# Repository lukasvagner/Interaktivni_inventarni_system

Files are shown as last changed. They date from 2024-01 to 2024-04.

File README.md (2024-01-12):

# Interaktivní inventární systém
## Anotace:
Bylo by to sledování krabiček. Systém by měl využívat vývojovou desku Raspberry Pi Zero, na které běží webserver. Tento webserver umožní vidět, které položky chybí a kdo si je vypůjčil. 
Každá krabička by měla své místo ve skříni a bude fungovat jako šuplík. U každého šuplíku by byl umístěn senzor, pravděpodobně infračervený (IR), který by sledoval, zda je krabička na svém místě. Dále by byla RGB LED pro zobrazování stavu a navigaci, kde danou položku vrátit.
Když uživatel vyjme krabičku, bude potřebovat se přihlásit tím, že přiloží svou identifikační kartu (RFID) k čtečce, kterou běžně používá ve škole. Tato informace spolu s číslem nebo názvem krabičky bude uložena do databáze spolu s datem a časem výpůjčky.

## Hardware
Budeme používat několik komponentů:
<ol>
  <li>Mozek všeho raspberry pi zeroWH - <a href="https://rpishop.cz/raspberry-pi-zero/685-raspberry-pi-zero-wh-4250236816296.html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">RPIShop</a><ul>
  <li>W značí že obsahuje čip na bezdrátové rozhraní</li>
  <li>H značí předem instalovaný header</li>
  
  </ul></li>
  <li>Nfc/Rfid čtečka na karty</li>
  <li>Senzor světla <ul>
    <li>Budeme nejspíš používat TCRT5000 - <a href="https://pdf1.alldatasheet.com/datasheet-pdf/download/26406/VISHAY/TCRT5000.html">DATASHEET</a></li>
    <li>používá se jako senzor ke kontrole zda jsou krabičky uloženy či nikoliv</li>
  </ul>
  </li>
  <li>Individuálně adresovatelné diody WS2812B k navigaci kam vracet krabičky<a href="https://pdf1.alldatasheet.com/datasheet-pdf/download/1179113/WORLDSEMI/WS2812B.html">DATASHEET</a> </li>
</ol>
 
## Funkčnost
Po přiložení karty načtená karta na 5s v této době si můžete vzít co chcete a bude ulozeno id karty pro případné problémy.
Při vracení karta neni potřeba jen načtete rfid chip na boxu a vložíte box na místo kde bliká led.
### Stavy
<ul>
<li>zelená: Box na svém místě</li>
<li>červená: Box ukraden nebo vložen na špatné místo</li>
<li>modrá: Box vypůjčen správně</li>
<li>oranžová: Box vypůjčen zatím není nahrána karta je tam čas 10sna to ji nahrát</li>
<li>blikající oranžová: Značí na jaké místo box vrátit</li> 
</ul>

## Progress update:
<ul>
  <li>30.11.23- Objednáno RaspberryPi Zero W</li>
  <li>15.12.23- Objední zbytku</li>
  <li>26.12.23- Funkční systém se čtečkou nfc a jedním senzorem</li>
  <li>02.01.24- Funkční systém se základním výpisem na server a psaní data logu do .txt</li>
  <li>04.01.24- Všechno přišlo</li>
  
</ul>

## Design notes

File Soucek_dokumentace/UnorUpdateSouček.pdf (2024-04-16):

## Vyšší odborná škola

a Střední průmyslová škola elektrotechnická,

## Plzeň, Koterovská 85

## Ročníková práce s obhajobou

Téma: | Inteligentní Inventární systém
Autor práce: | Jakub Souček
Třída: | 3.M
Vedoucí práce: | Prof. Ing. Pavel Jedlička
Dne: | 31.1.2024

## Hodnocení:

## Z A D Á N Í R O Č N Í K O V É P R Á C E

Školní rok | 2023/ 2024
Studijní obor | 78-42-M/01 Technické lyceum
Jméno a příjmení | Jakub Souček
Třída | 3.M
Předmět | Kybernetika
Hodnoceno v předmětu | Kybernetika
Téma | Inventární systémy
Obsah práce | • Návrh velikosti a tvaru krabiček o • Hardwarová část • nakoupení potřebných součástek, propojení senzorů a ledek s mikropočítačem. • Uživatelské rozhraní • zavedení přihlašovacího systému s kartami/čipy • Vytvoření webového rozhraní pro sledování stavu krabiček • zjišťování chybějících položek a ovládání funkcí
Zadávající učitel Příjmení, jméno | Jedlička Pavel

## Podpis zadávajícího učitele

Termín odevzdání | 30. dubna 2024

## Vyšší odborná škola a

Střední průmyslová škola elektrotechnická Plzeň,

## Koterovská 85

V Plzni dne: 30. 11. 2023 | Mgr. Vlas]mil Volák ředitel školy

## Anotace

Cílem této rovníkové práce by bylo vyrobit systém, který by kontroloval, kdo a kdy si vypůjčil nějakou položku ze skříně. Jednotliví lidé by se ověřovali stejnou identifikační kartou jako používají ve školním systému doposud. Dále by byla možnost podívat se na obsah skříně online na webserveru, ve kterém by byla vidět všechna data o různých Výpůjčkách jako je: čas a UID karty uživatele.

„Prohlašuji, že jsem tuto práci vypracoval samostatně a použil(a) literárních pramenů a informací, které cituji a uvádím v seznamu použité literatury a zdrojů informací.“

V Plzni dne: | Podpis:

## Obsah

1 Úvod | 5
2 Návrh | 5

4

## 1 Úvod

Jako žák prestižní střední školy SPŠE vnímám jako závažný problém, kterým je „bordel“ v úložném

prostoru v učebnách dílen. Jeden z hlavních problému jsou neustálé ztráty součástek a časté krádeže výukového materiálu. Proto jsem se já a můj kamarád Lukáš Vágner s tímto problémem něco udělat. Tento systém umožňuje sledování obsahu inventáře prostřednictvím Optických senzorů, které detekují přítomnost předmětů v určité vzdálenosti. Jeho potenciál spočívá v prevenci krádeží a monitorování obsahu skříně. Cílem této ročníkové práce je navrhnout a implementovat inteligentní inventární systém, schopný detekovat předměty v blízkosti senzorů TCRT-5000. Účelem

je vytvořit funkční prototyp, který monitoruje obsah skříně a poskytuje informace o přítomnosti a množství jednotlivých předmětů. Tento systém může najít uplatnění v různých oblastech, včetně skladů, kanceláří a domácností. Pokud máte další otázky, neváhejte se zeptat. Děkuji za upřesnění ohledně použití NFC čipů a přístupových karet. Tyto technologie využívají bezkontaktní přenos dat prostřednictvím rádiových vln¹²³. Jsou běžně využívány v přístupových a docházkových sys-

témech a mohou být aplikovány i ve Vašem projektu pro označení vypůjčených předmětů. bla bla bla dále to domyslím/přepíšu

2 | Návrh
2.1 | Hardware

5

2.1.1 Výběr komponentů

- Raspberry Pi Zero WH
- Miniaturní velikost: Raspberry Pi Zero WH je extrémně kompaktní počítač, který se
| vejde do rozměrů pouhých (66,0 mm x 30,5 mm x 5,0 mm). Tato malá velikost je ideální
| přesně pro níš projekt.
- Bezdrátová konektivita: Raspberry Pi Zero WH je vybaven Wi-Fi 802.11n a Bluetooth
| 4.1, což umožňuje snadnou komunikaci s jinými zařízeními.
- GPIO piny: Na desce je 40 GPIO pinů, které umožňují připojení dalších periferií a
| rozšíření.

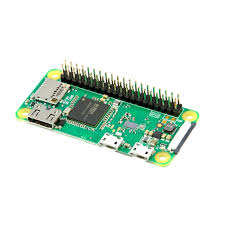
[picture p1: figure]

Obrázek 1: : Raspberry Pi Zero WH

6

- Pn532 - NFC/RFID čtečka karet
- Frekvence a podpora NFC tagů: NFC čtečka tagů PN532 pracuje na frekvenci 13,56 MHz a podporuje takzvané NFC tagy. Za tagy se považují všemožné RFID karty, žetony, samolepky atd.
- Rozhraní: NFC čtečka PN532 umí komunikovat pomocí tří různých rozhraní: HSU, I2C a SPI. Můžete si vybrat to, které nejlépe vyhovuje vašemu projektu.
- Jednoduchost zapojení: Pro úspěšné propojení NFC čtečky s Raspberry stačí zapojit celkem čtyři vodiče. Propojíme GND se zemí Arduina, VCC s 3V3 Arduina, SDA s pinem A4 a SCL s pinem A5.

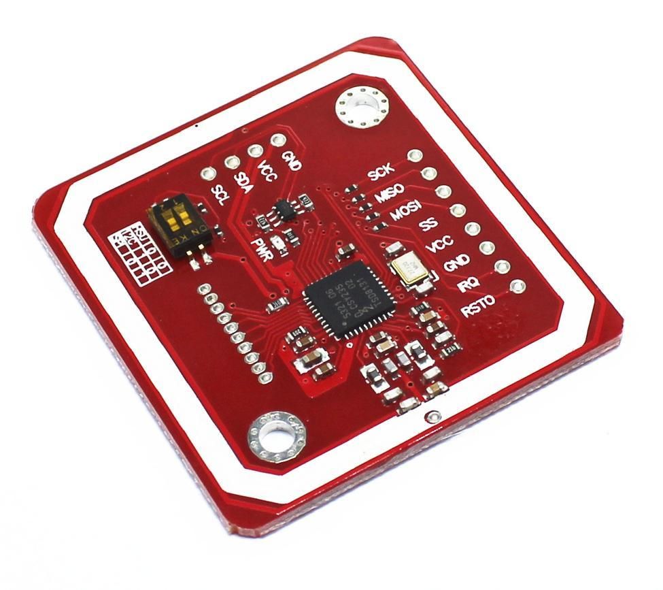
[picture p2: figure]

Obrázek 2: : Pn532 - NFC/RFID čtečka karet

7

- Pcf-8575 - 16bit I/O expander pinů připojený přes 12C
- Rozšiřuje počet I/O pinů: PCF8575 je 16bitový I/O expander, který umožňuje rozšíření počtu vstupně/výstupních pinů. Tuhle součástku jsme právě proto vybrali.
- Komunikace přes I2C: PCF8575 komunikuje pomocí sběrnice I2C (Inter-Integrated Circuit). Tato dvousměrná sběrnice umožňuje snadnou komunikaci s mikrokontroléry a dalšími zařízeními.
- Napájení: PCF8575 pracuje v rozmezí napětí od 2,5 V do 5,5 V. To znamená, že je vhodný pro různé napájecí úrovně.

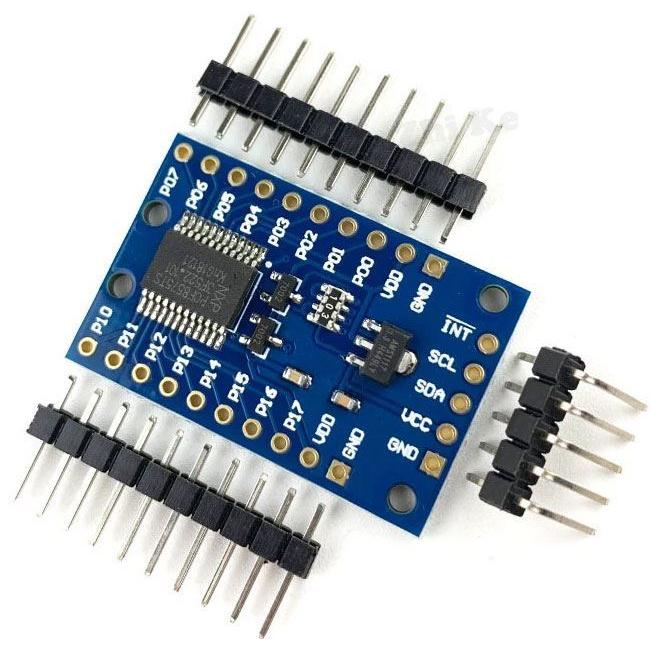
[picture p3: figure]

Obrázek 3: : 16-bit expander Pcf-8575

8

- TCRT-5000 - Infračervený optický senzor
- Reflektivní optický senzor: TCRT5000 je reflektivní senzor, což znamená, že kombinuje infračervený vysílač a fototranzistor v jednom pouzdře. Tento senzor je určen k detekci odrazů světla od povrchů.
- Pracovní vzdálenost: Má špičkovou pracovní vzdálenost 2,5 mm. To znamená, že může detekovat předměty ve vzdálenosti až 2,5 mm od senzoru.
- Filtr blokující denní světlo: TCRT5000 je vybaven filtrem, který blokuje viditelné světlo.
- Jednoduchost zapojení: Senzor se připojuje skrz desku a pracuje s napětím 5 V.

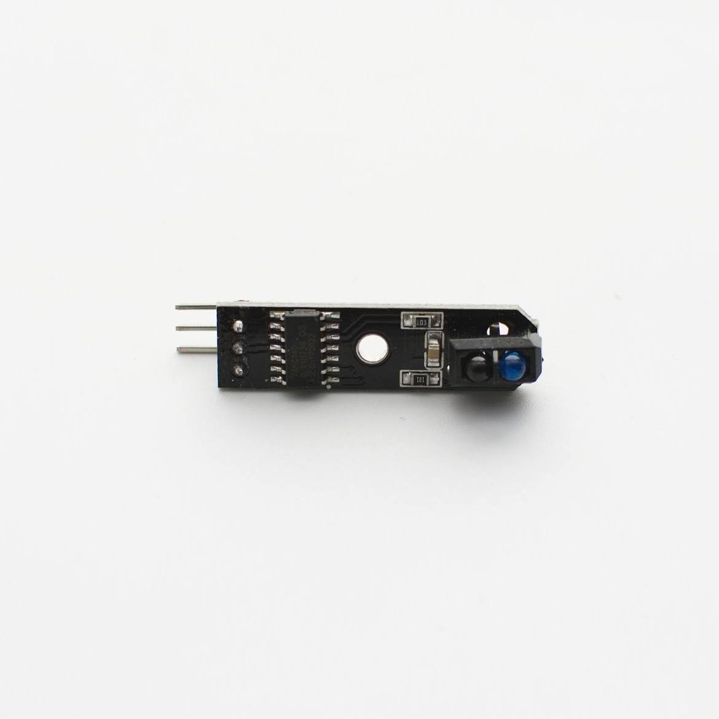
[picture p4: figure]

Obrázek 4: : Optický senzor TCRT-5000

9

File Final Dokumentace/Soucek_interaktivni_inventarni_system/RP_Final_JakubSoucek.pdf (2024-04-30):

## Vyšší odborná škola

a Střední průmyslová škola elektrotechnická,

## Plzeň, Koterovská 85

## Ročníková práce s obhajobou

Téma: | Inteligentní Inventární systém
Autor práce: | Jakub Souček
Třída: | 3.M
Vedoucí práce: | Prof. Ing. Pavel Jedlička
Dne: | 30.4.2024

## Hodnocení:

## Z A D Á N Í R O Č N Í K O V É P R Á C E

Školní rok | 2023/ 2024
Studijní obor | 78-42-M/01 Technické lyceum
Jméno a příjmení | Jakub Souček
Třída | 3.M
Předmět | Kybernetika
Hodnoceno v předmětu | Kybernetika
Téma | Inventární systémy
Obsah práce | • Návrh velikosti a tvaru krabiček o • Hardwarová část • nakoupení potřebných součástek, propojení senzorů a ledek s mikropočítačem. • Uživatelské rozhraní • zavedení přihlašovacího systému s kartami/čipy • Vytvoření webového rozhraní pro sledování stavu krabiček • zjišťování chybějících položek a ovládání funkcí
Zadávající učitel Příjmení, jméno | Jedlička Pavel

## Podpis zadávajícího učitele

Termín odevzdání | 30. dubna 2024

## Vyšší odborná škola a

Střední průmyslová škola elektrotechnická Plzeň,

## Koterovská 85

V Plzni dne: 30. 11. 2023 | Mgr. Vlas]mil Volák ředitel školy

## Anotace

Cílem této ročníkové práce je vyrobit systém, který by kontroloval, kdo a kdy si vypůjčil nějakou položku ze skříně. Jednotliví lidé by se ověřovali stejnou identifikační kartou jako se používá ve školním systému doposud. Dále by byla možnost se podívat na obsah skříně online na webserveru, ve kterém by byla vidět všechna data o různých výpůjčkách jako je: čas a UID karty uživatele.

„Prohlašuji, že jsem tuto práci vypracoval samostatně a použil literárních pramenů a informací, které cituji a uvádím v seznamu použité literatury a zdrojů informací. Souhlasím s využitím mé práce učiteli VOŠ a SPŠE Plzeň k výuce.“

V Plzni dne: | Podpis:

## Obsah

1 Úvod | 5
2 Návrh | 5
3 Hardware | 6
4 Zapojení | 9
5 3D design | 11
6 Realizace a sestavení | 13
7 Závěr | 15

4

## 1 Úvod

Naším hlavním úkolem v rámci ročníkové práce je vytvoření inteligentního inventárního systému pro školní dílny, který umožní efektivní evidenci a správu vypůjčených položek.
| Ve školních dílnách často naražíme na problémy spojené s nedbalým půjčováním nástrojů a
materiálů, což často vede k neuspořádanosti a ztrátám. Náš záměr je tuto situaci zlepšit a zajistit, aby inventář dílen byl lépe spravován a účinněji využíván.
| V rámci hardwarové části našeho projektu jsme vyvinuli a implementovali policový systém,
který systematicky uskladňuje a identifikuje položky prostřednictvím standardních krabic s čipy. Tento systém využívá kombinaci NFC/RFID čtečky pro rozpoznání čipů a identifikačních karet uživatelů. Kromě toho je vybaven senzory, které monitorují umístění krabic a inteligentními LED diodami, které signalizují stav položek.
| Na softwarové straně jsme vyvinuli uživatelsky přívětivý systém pro správu inventáře přes
webové rozhraní. Tento systém umožňuje snadné půjčování, vrácení a sledování položek. Díky němu mohou studenti a učitelé efektivně spravovat inventář a monitorovat výpůjčky i případné problémy s položkami.

## 2 Návrh

Zpočátku jsme zamýšleli o vytvoření jednoduchého systému, který by usnadnil uskladnění krabiček a sledování jejich stavu pomocí senzorů. Vytvořili jsme tak několik návrhů, jak by mohla taková krabička vypadat.
| Design poliček byl několikrát přepracován, než jsme našli ideální řešení. Nejprve jsme zamýšleli
vyrobit celý box na míru vytištěný na 3D tiskárně, ale z časových a hlavně i finančních důvodů jsme zvolili mnohem ekologičtější řešení. Zkompletovali jsme box z OSB desek, které se dají pořídit téměř v každém hobbymarketu. Jednotlivé poličky jsou přesně na míru nařezané plastové lišty a pomyslná záda našeho boxu jsou 3D vytištěné zarážky z PLA se zapuštěnými senzory a LED přesně upravené podle konkrétních požadavků.
| Elektroniku jsme také navrhovali s ohledem na snadnou výměnu, pokud by bylo potřeba s
důrazem na její cenovou dostupnost a spolehlivost. Tento proces návrhu prošel několika koly úprav, avšak nakonec jsme dosáhli řešení, které splňovalo naše požadavky a kritéria.

5

## 3 Hardware

Jelikož jsme se při výběru ideálních hardwarových součástek soustředili na co nejlehčí duplikaci celého modulu, vybírali jsme převážně hotové moduly a pasivní součástky. Komponenty, které jsme vybrali, mají schopnost pracovat s napájením buď 3.3V nebo 5V, což usnadňuje jejich začlenění do systému. Jako hlavní prostředek komunikace jsme zvolili I2C, což zajistí efektivní a spolehlivou výměnu dat mezi jednotlivými součástkami.

### 3.1 Komponenty

- Raspberry Pi Zero WH - Jedním z hlavních důvodů proč jsme vybrali právě tento
| jednočipový mikropočítač, je zakomponovaná anténa pro Bluetooth a Wifi, (W) díky které náš systém může v reálném čase sdílet informace s webem. Raspberry také podporuje programovací jazyk Python, ve kterém je náš kód. (Raspberry Pi Zero Dokumentace 2024)


Obrázek 1: Raspberry Pi Zero WH

6

- Pn532 - NFC/RFID čtečka karet - Pn532 je NFC čtečka tagů, která pracuje na frekvenci 13,56 MHz. Za tagy se považují všemožné RFID karty, žetony, samolepky atd. NFC čtečka Pn532 umí komunikovat pomocí tří různých rozhraní: HSU, I2C a SPI. Pro náš projekt jsme zvolili I2C pro její efektivní spolehlivou výměnu dat.(Pn532 návod 2024)


Obrázek 2: Pn532 - NFC/RFID čtečka karet

- Pcf-8575 - 16bit I/O expander pinů připojený přes I2C - PCF-8575 rozšiřuje rozsah vstupů a výstupů Raspberry Pi, což je praktické pro naši práci, kde je více senzorů. Využili jsme jeho podporu I2C rozhraní a možnost konfigurace různých adres, která umožňuje připojení více těchto expandérů k jedinému zařízení.(PCF-8575 Dokumentace 2024)


Obrázek 3: 16-bit expander Pcf-8575

7

- TCRT-5000 - Infračervený optický senzor - TCRT5000 je reflektivní senzor, což znamená, že kombinuje infračervený vysílač a fototranzistor v jednom pouzdře. Tento senzor je určen k detekci odrazů světla od povrchů. TCRT5000 je vybaven filtrem blokující denní světlo. Senzor je připojen skrz desku a pracuje s napětím 5 V. (TRTC-5000 dokumentace 2024)


Obrázek 4: Optický senzor TCRT-5000

8

### 3.2 Vedlejší komponenty

Kromě hotových modulů jsme začlenili do naší aplikace několik pasivních/vedlejších součástek:

- LED diody: Pro vizuální signalizaci různých stavů jsme využili 2 LED diody - červenou a zelenou.
- Buzzer: Pro zvukovou signalizaci jsme začlenili bzučák, který je schopen generovat různé zvukové signály podle aktuálního stavu systému. Buzzer přispívá k celkové interaktivitě a uživatelskému povědomí o událostech v systému.

## 4 Zapojení

Za použití programu Fritzing jsme sestavili schéma zapojení. Na obrázku 12

- Pcf-8575 - 16bit expander pinů je zapojen do Raspberry Pi Zero WH takto:

VCC - 3V3 Power
SDA - BCM 2 (SDA)

SCL - BCM 3 (SCL)

Propojení VCC - 3V3 Power zajišťuje napájení součástky o napětí 3V. Propojení SDA -BCM 2 zajistí správný přenos informací. To samé i u propojení SCL - BCM

- Pn532 - NFC čtečka do Raspberry Pi Zero WH takto:

GND - GND

VCC - 3V3 Power
TX - BCM 2 (SDA)

RX - BCM 3 (SCL)

Propojení GND - GND nám obvod uzemní. Propojení VCC - 3V3 Power zajišťuje napájení součástky o napětí 3V. Propojení TX - BCM 2 zajistí správný přenos informací, to samé i u propojení RX - BCM.

9

- RGB led do Raspberry Pi Zero WH takto:

+5V - 5V Power
DATAIN - BCM 18 (PWM0)

GND - GND

Propojení GND - GND nám obvod uzemní. Propojení +5V - 5V Power zajišťuje napájení součástky o napětí 5V, které je nutné pro napájení RGB led. Propojení DATAIN - BCM 18 zajistí správný přenos informací.

- Senzory TCRT-5000 do Pfc-8575:

GND - GND

VCC - VCC

Do - PO0-PO17

Propojení GND - GND nám obvod uzemní. Propojení VCC - VCC zajišťuje napájení součástky o napětí 3V. PO0-PO17 znamená, že každý senzor je individuálně zapojen do expanderu PCF8575 to zajistí přenos dat do Raspberry.

10

## 5 3D design

Všechny součásti jsme navrhovali v 3D CAD softwaru Inventor®, kde jsme je poskládali

do celkové sestavy, přesně podle toho, jak by měla celá polička vypadat. Následně jsme jednotlivé díly vytiskli na 3D tiskárně nebo je vyřezali pilou. Zbylé součástky jsme pořídili v hobbymarketu a nakonec jsme všechny díly sestavili podle plánovaného návrhu. Všechny modely je možno najít na:

https : //github.com/lukasvagner/Interaktivniinventarnisystem/tree/main/3D

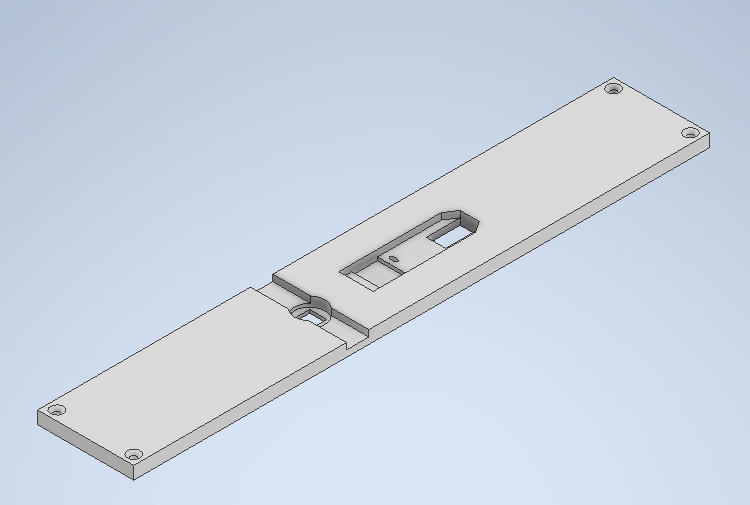
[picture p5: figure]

Obrázek 5: : Model zarážky boxu

Po několika měřeních a prototypech jsme přišli s finální velikostí a rozměry.

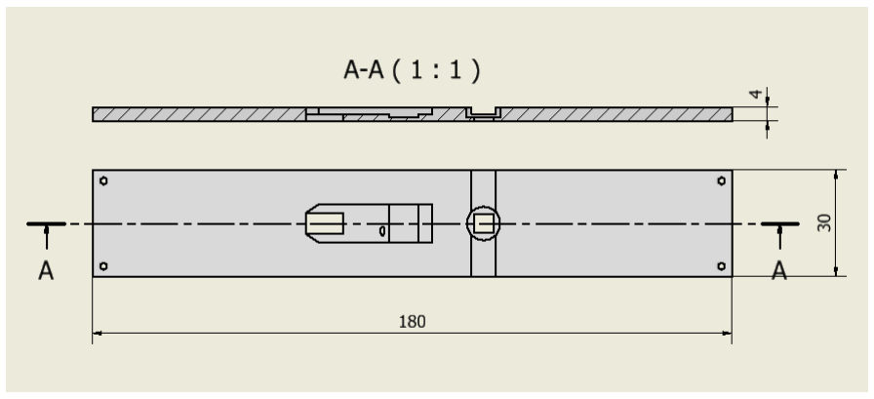
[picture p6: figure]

Obrázek 6: : Výkres zařážky boxu

11

Box se skládá z pěti dřevotřískových desek, nařezaných plastových lišt a zarážky vyrobené z PLA.

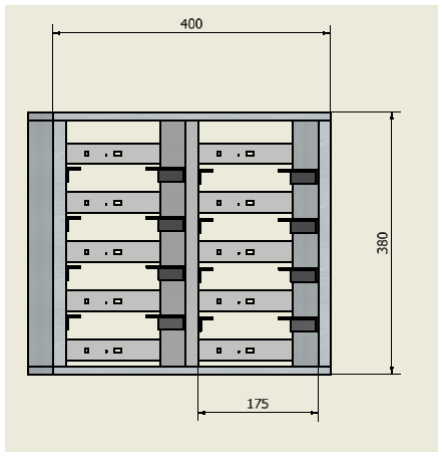
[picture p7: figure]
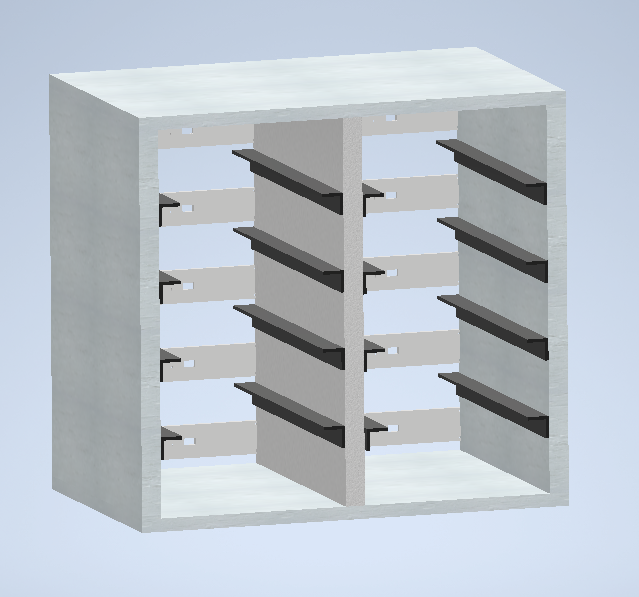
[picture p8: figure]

Obrázek 7: Model boxu a výkres

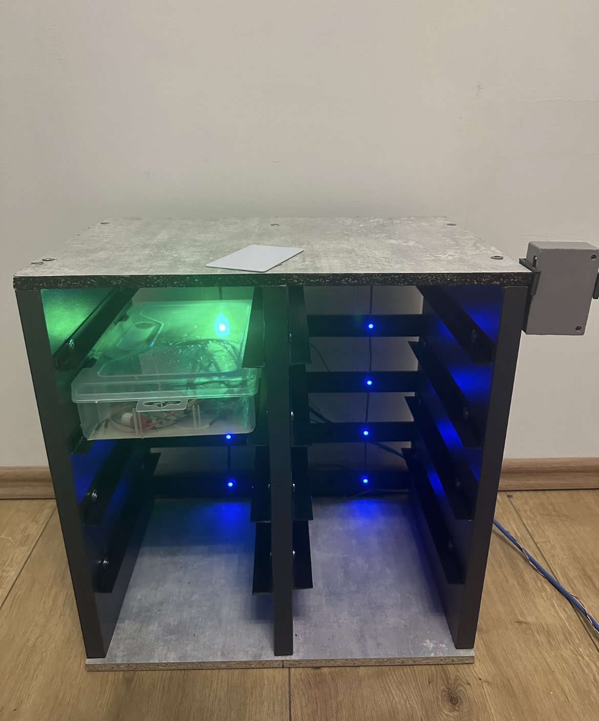
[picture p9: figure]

Obrázek 8: Box - finální verze

12

6 | Realizace a sestavení
6.1 | Zadní část boxu

Ze zadní části boxu najdeme 10 zarážek se senzorem. Dále je zde shromažďovací bit expander, ze kterého všechna data jdou do ovládací krabičky. Dále se zde nachází shromažďovací

expander bitů, z něhož všechna data směřují do ovládací krabičky.

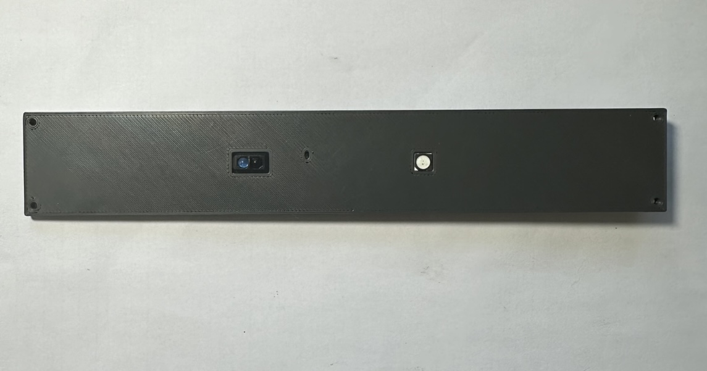
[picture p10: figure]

Obrázek 9: Přední část zarážky

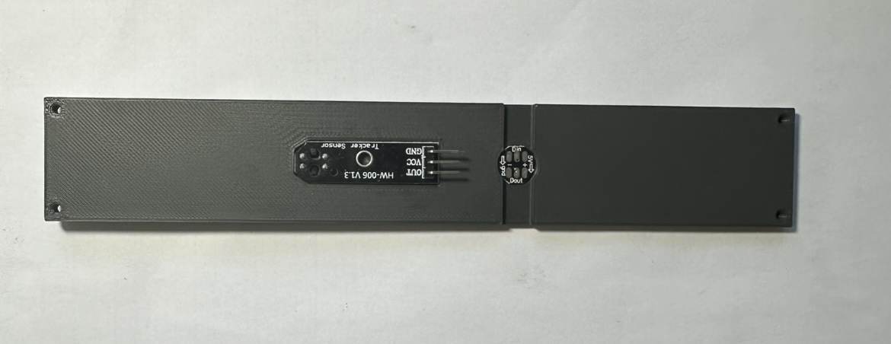
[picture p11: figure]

Obrázek 10: Zadní část zarážky

13

### 6.2 Ovládácí krabička

Zařízení je usazené v připraveném 3D tištěném boxu, jenž zabezpečuje ochranu jeho niterních součástí. Na zadní straně boxu se nachází konektor vyhrazený pro propojení senzorů se shromažďovačem dat.

Vnitřek zařízení hostí NFC čtečku, spojenou s Raspberry Pi Zero přes pájivé pole. Tato Raspberry Pi Zero plní úlohu hlavní řídící jednotky, která zpracovává informace z NFC čtečky a řídí celý systém.

Dvě LED diody, jedna červená a druhá zelená, jsou namontovány na vnější straně zařízení, sloužící k vizuální signalizaci stavu. Buzzer pak zajišťuje zvukovou signalizaci, jako součást celkového varování případných problémů.

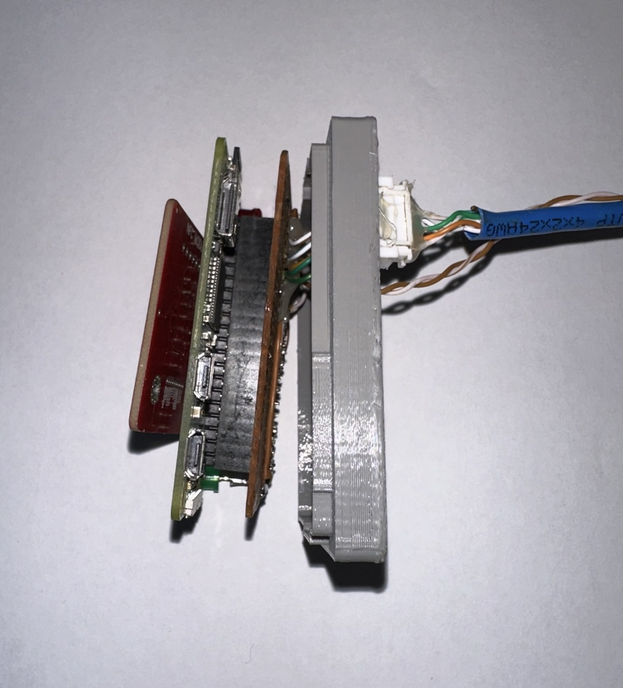
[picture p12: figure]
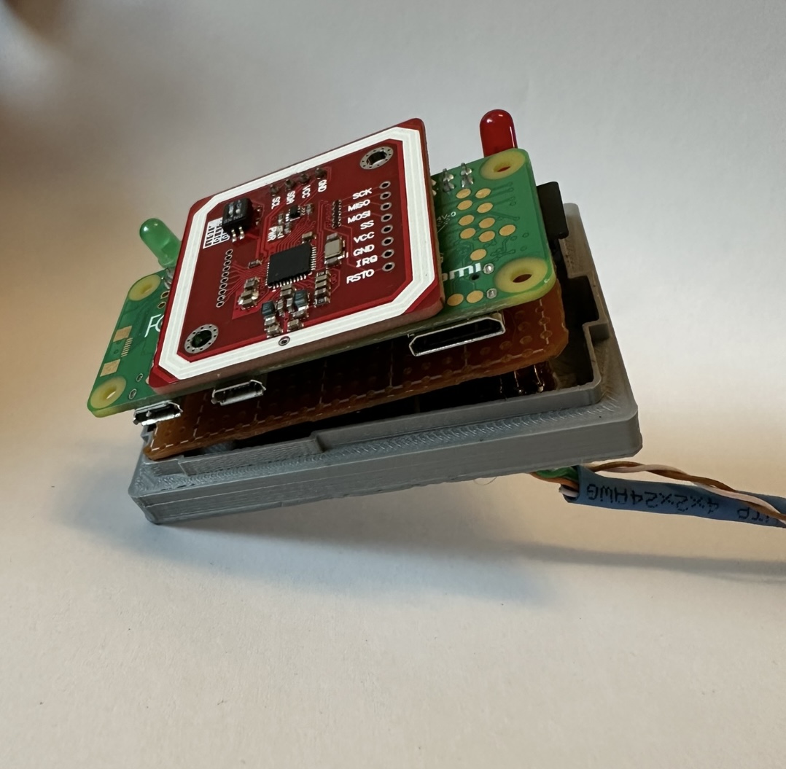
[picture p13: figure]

Obrázek 11: Ovládací krabička zpředu a z boku

14

## 7 Závěr

Naším záměrem bylo vytvořit efektivní systém pro správu inventáře, který by usnadňoval půjčování a sledování elektronických komponent v prostředí školních dílen s možností kontroly aktuální dostupnosti na internetovém rozhraní.
| Systém nabízí mnoho funkcionalit, které řeší problémy s organizací komponentů ve školních
pracovištích. Webové rozhraní poskytuje jasnou vizualizaci obsahu každého úložného místa, což facilituje vyhledávání potřebných dílů. Uživatelé mohou z webu označit požadované místo, které poté zvýrazní barevné osvětlení, zjednodušující rychlé nalezení. Přidávání záznamů o nedávných výpůjčkách pak umožňuje efektivní sledování a správu vypůjčených součástek, včetně řešení případných poškození.
| Přestože systém je téměř připraven k nasazení, vyžaduje několik úprav. Je třeba doladit funk-
cionalitu pro změnu názvu úložného místa a resetování jeho stavu, aby byly tyto operace dostupné pouze pro ověřené uživatele a zabránilo se tak jejich zneužití.
| Další vylepšení by mohlo zahrnovat integraci systému se školní databází, což by zajistilo
správnou identifikaci všech uživatelů pomocí jejich ID karet a přiřazení odpovídajících údajů k jejich osobám.
| Celkově je náš systém navržen tak, aby byl intuitivní a snadno ovladatelný. Díky vizuálním
a zvukovým signálům uživatelé snadno poznají, kam vrátit půjčené předměty a jsou upozorněni, pokud se objekt nenachází na vhodném místě. Tato jednoduchost a intuitivnost by měla přispět ke zvýšení efektivity a snížení chybovosti při používání systému.
| Dalším krokem bude zavedení tohoto systému do praxe ve školních dílnách a jeho optimalizace
pro co nejlepší výkon a použitelnost pro všechny uživatele.

15

## Seznam použité literatury a zdrojů informací

PCF-8575 Dokumentace (2024). url: https : / / michiel . vanderwulp . be / domotica /

Modules/IO-expander-PCF8575/ (https://michiel.vanderwulp.be/domotica/Modules/IO-expander-PCF8575/) (cit. 28. 04. 2024).

Pn532 návod (2024). url: https://www.elechouse.com/elechouse/images/product/

PN532_module_V3/PN532_%20Manual_V3.pdf (https://www.elechouse.com/elechouse/images/product/PN532_module_V3/PN532_%20Manual_V3.pdf) (cit. 28. 04. 2024).

Raspberry Pi Zero Dokumentace (2024). url: https://www.raspberrypi.com/documentation/

computers/raspberry-pi.html#raspberry-pi-zero-w (https://www.raspberrypi.com/documentation/computers/raspberry-pi.html#raspberry-pi-zero-w) (cit. 28. 04. 2024).

TRTC-5000 dokumentace (2024). url: https://electropeak.com/learn/interfacing-

tcrt5000 - ir - black - and - white - line - tracking - sensor - with - arduino/ (https://electropeak.com/learn/interfacing-tcrt5000-ir-black-and-white-line-tracking-sensor-with-arduino/) (cit.
28. 04. 2024).

16

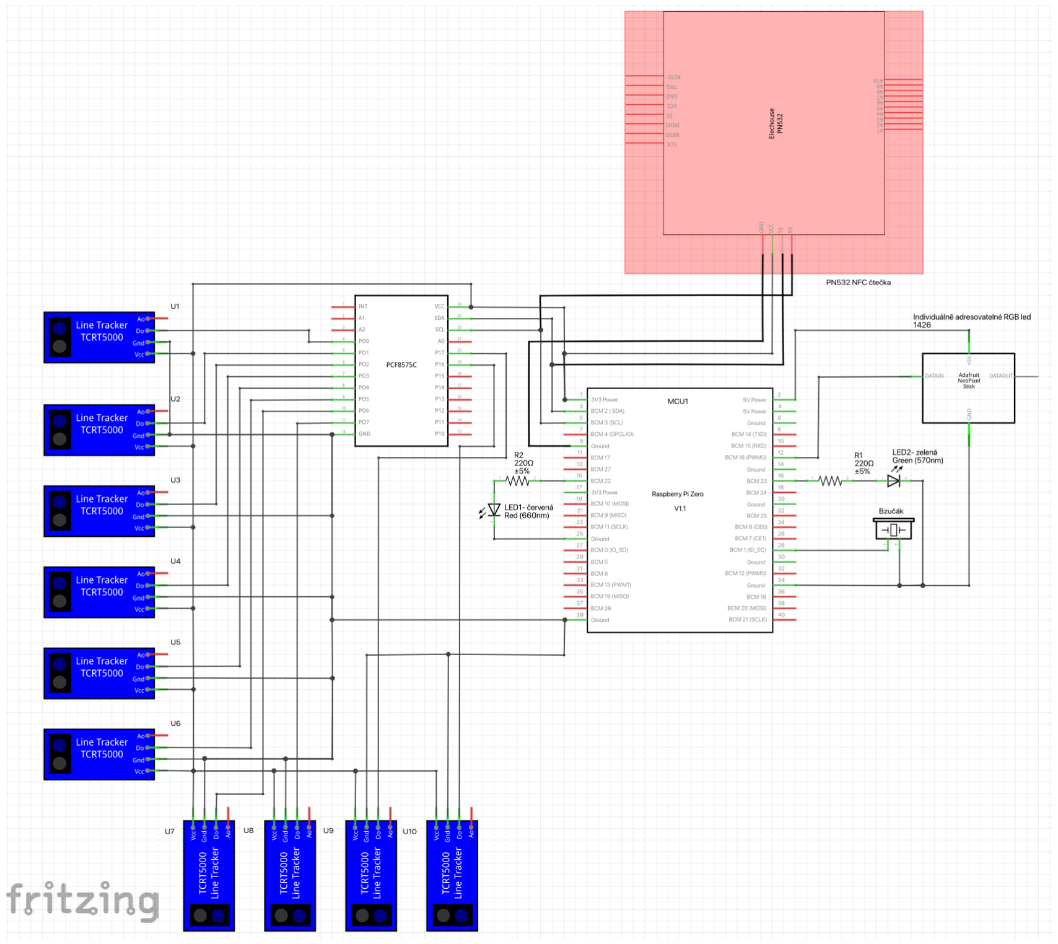
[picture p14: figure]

Obrázek 12: Schéma elektrického zapojení

Obrázek je možno najít na Githubu v plném rozhlišení:
https : //github.com/lukasvagner/Interaktivniinventarnisystem/blob/main/Schematic.png

17

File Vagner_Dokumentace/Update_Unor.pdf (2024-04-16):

## Vyšší odborná škola

a Střední průmyslová škola elektrotechnická,

## Plzeň, Koterovská 85

## Ročníková práce s obhajobou

Téma: | Inteligentní inventární systém
Autor práce: | Lukáš Vágner
Třída: | 3.M
Vedoucí práce: | Ing. Pavel Jedlička
Dne: | 10. března 2024

## Hodnocení:

## Z A D Á N Í R O Č N Í K O V É P R Á C E

Školní rok | 2023/ 2024
Studijní obor | 78-42-M/01 Technické lyceum
Jméno a příjmení | Lukáš Vágner
Třída | 3.M
Předmět | Kybernetika
Hodnoceno v předmětu | Kybernetika
Téma | Inteligentní Inventární systémy
Obsah práce | Návrh velikosti a tvaru krabiček o Návrh designu stojanu na krabičky o Výroba samostatného stojanu o Výroba krabice na uložení mikropočítače a čtečky karet/čipu Softwarová část o Vymyslet si schéma kódu co mají dělat jed-notlivé části o Naprogramovat a zprovoznit funkčnost ce-lého systému zatím bez web-aplikaces Uživatelské rozhraní o zavedení přihlašovacího systému po-mocí kartami/čipy o Vytvoření webového rozhraní pro sledo-vání stavu inventárního systému o vizualizace inventury
Zadávající učitel Příjmení, jméno | Ing. Jedlička Pavel

## Podpis zadávajícího učitele

Termín odevzdání | 30. dubna 2024
V Plzni dne: 30. 11. 2023 | Mgr. Vlastimil Volák ředitel školy

## Vyšší odborná škola a

Střední průmyslová škola elektrotechnická Plzeň,

## Koterovská 85

## Anotace

Cílem této ročníkové práce by bylo vyrobit systém, který by kontroloval, kdo a kdy si vypůjčil nějakou položku ze skříně. Jednotliví lidé by se ověřovali stejnou identifikační kartou jako používají ve školním systému doposud. Dále by byla možnost podívat se na obsah skříně online na webserveru, ve kterém by byla vidět všechna data o různých výpůjčkách jako je: čas a UID karty uživatele.

„Prohlašuji, že jsem tuto práci vypracoval samostatně a použil(a) literárních pramenů a informací, které cituji a uvádím v seznamu použité literatury a zdrojů informací.“

V Plzni dne: | Podpis:

## Obsah

1 Úvod | 5
2 Návrh | 5
3 Hardware | 5
4 Software | 9
5 Text s citacemi | 11

4

## 1 Úvod

Úvod k této práci je zaměřen na návrh a implementaci inteligentního inventárního systému, který

slouží k evidenci a správě vypůjčených položek ve školních dílnách. Cílem této práce je vytvořit systém, který monitoruje, kdo si půjčuje danou položku a kdy k tomu došlo. Tento systém zahrnuje hardwarovou část, zahrnující návrh stojanů pro uskladnění krabiček, a softwarovou část, která zajišťuje správu a sledování inventáře, který je vidět jak fyzicky tak na webu.

2 | Návrh
2.1 | 3D design
3 | Hardware

5

3.1 | Výběr komponentů
3.1.1 | Raspberry pi zero WH
- W - značí že deska obsahuje vestavěnou anténu pro Wifi a Bluetooth pro nás důležité z
| důvodu potřeby webového rozhraní
- H - Značí že deska má předinstalovaný GPIO header
- tuto desku jsme vybrali hlavně kvůli jejím malým rozměrům, dostatečnému výkonu pro naše
| využití a vestavěné anténě pro Wifi.

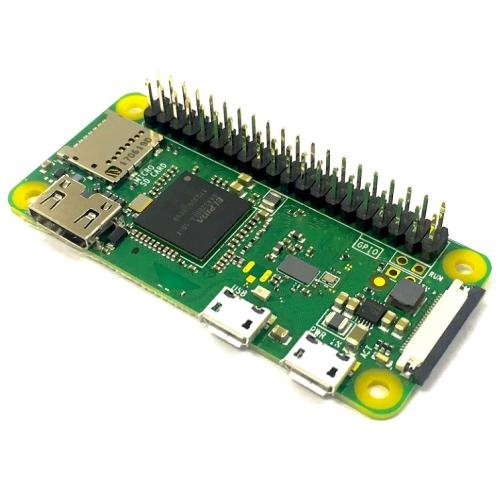
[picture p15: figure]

Obrázek 1: Raspberry pi zero WH

3.1.2 Pn532 - NFC/RFID čtečka karet

- Připojená k RPi pomocí I2C na defaultní adrese 0x24
- Tuto čtečku jsme vybrali kvůli její velké kompatibilitě s velkým množstvím různých ka-
| ret/čipů


Obrázek 2: NFC/RFID čtečka Pn532

6

3.1.3 Pcf-8575 - 16bit I/O expander pinů připojený přes I2C

- 16 pinový Input Output expander
- Připojený k RPi pomocí I2C na defaultní adrese 0x20
- Tento expander používáme ke sběru dat z jednotlivých senzorů TCRT-5000(viz níže)
| možnost připojit až 16 senzorů.
- Pokud by se chtěl systém rozšířit není problém přidat další expander nastavený na jinou
| adresu I2C

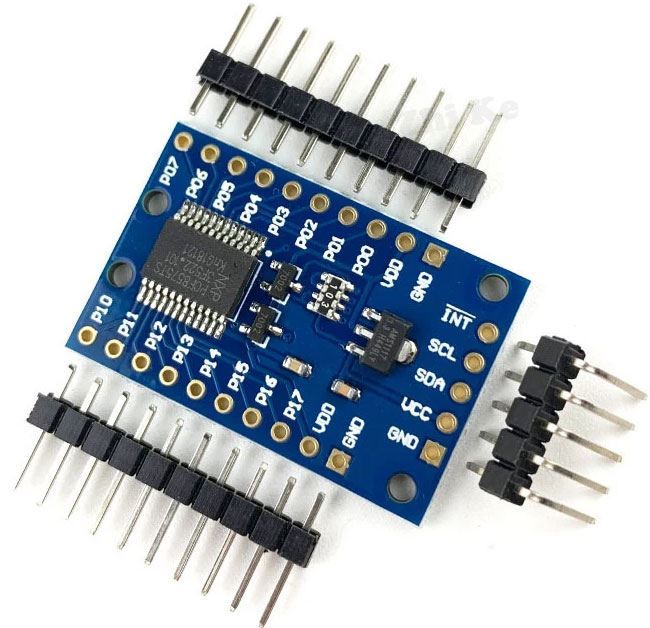
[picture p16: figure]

Obrázek 3: 16-bit expander Pcf-8575

3.1.4 TCRT-5000 - Infračervený optický senzor

- Senzor využívaný ke kontrole stavu jednotlivých pozic ve skříni
- výstup 1- při objektu před ním 0- když se před ním nic nenachází
- Jednou z nevýhod senzor nepozná když předmět který se před něj umístí bude tmavší barvy,
| protože barva pohltí světlo vyslané infračervenou led
- výstup senzoru připojen k Pcf-8575

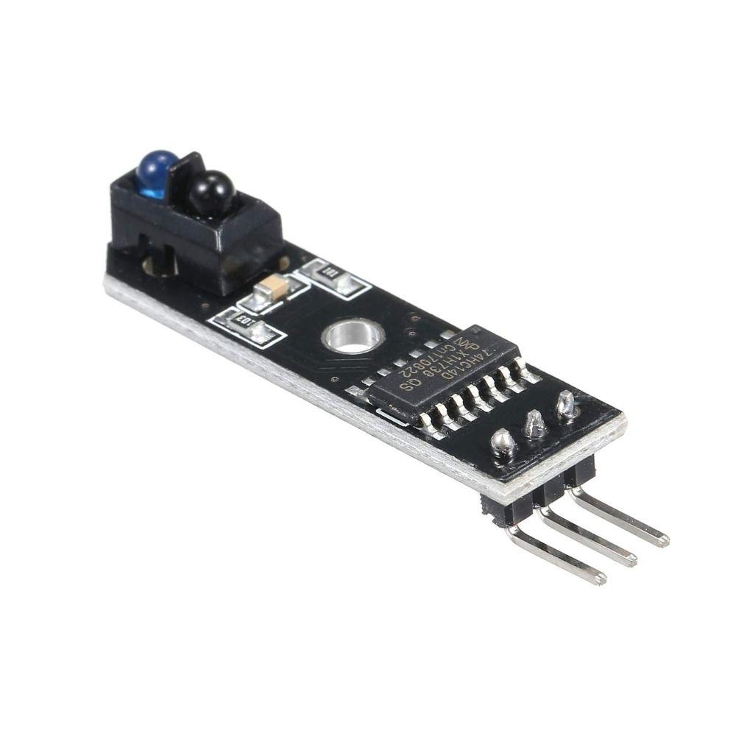
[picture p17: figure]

Obrázek 4: Optický senzor TCRT-5000

7

3.1.5 WS2812B - RGB led

- využívaná k signalizaci jednotlivých stavů na pozicích ve skříni
- vybrali jsem ji kvůli možnosti ovládání jednotlivých led zapojených v sérii za sebou pomocí
| jednoho datového vstupu připojenému k RPi

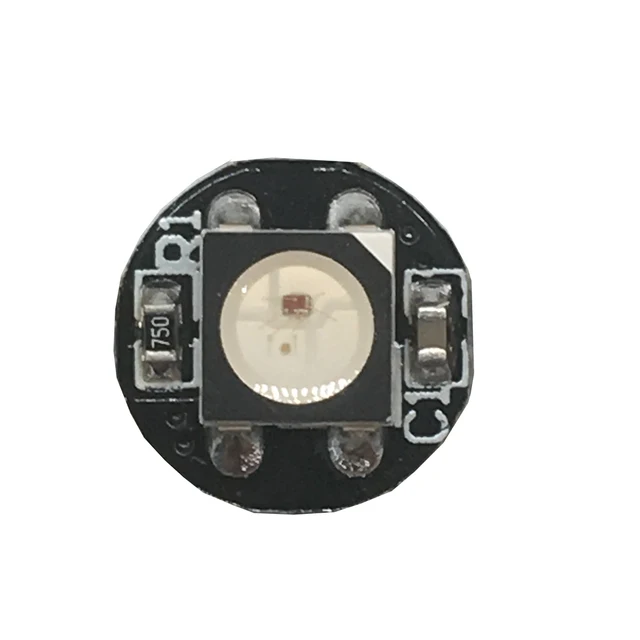
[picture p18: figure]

Obrázek 5: WS2812B

8

## 4 Software

Hlavní kód je psán v Pythonu. V kódu můžeme najít několik funkcí a řešení různých případů, které mohou nastat. Program běží pomocí knihovny threads ve dvou samostatných vláknech jedno pro samotné přihlašování a vypůjčování / vracení krabiček a druhý pro lokální webový server, který běží pomocí knihovny Flask.

### 4.1 1.Thread - Main

V hlavním (Main) vlákně najdeme:

- Check-card Neustálé sledování zda nebyla přiložena identifikační karta nebo NFC čip nalepený na boxu pokud se tak stane zavolá jiné funkce pokud byl přiložen čip nějaké z krabiček zavolá funkci Return-box (viz níže). Pokud bude přiložena jakákoliv jiná karta uloží dočasně její unikátní identifikační číslo.
- Check-change Neustále hlídá zda nějaký ze senzorů vzdálenosti nezaznamenal změnu stavu (1- krabička se zde nachází, 0 - krabička se zde nenachází). Pokud nastane změna stavu tak funkce postupně projíždí všechny možnosti. Nejdříve Byla krabička odstraněna
nebo | ji | někdo | vrátil.
Jestli že byla krabička odstraněna řešíme zda byl přihlášen uživatel, pokud ano poté se jen zapíše čas výpůjčky a identifikační číslo uživatele a vše je v pořádku. Pokud uživatel není přihlášen začne blikat podsvícení krabičky a přihlašovací zařízení a nastane 10 vteřinové okno kdy má uživatel možnost se přihlásit za předpokladu že se tak stane vše se zopakuje jako kdyby byl přihlášen. Pokud ne je box označen za ukradnutý a podsvícení políčka svítí červeně
dokud | se | nevrátí | nebo | tento | stav | není | zresetován.
Druhá možnost krabička byla vrácena v tomto případě se podívá zda předtím byl načten její čip pokud ano vše je v pořádku a zapíše se jen čas vrácení. Pokud předtím nebyla načtena podsvícení se rozsvítí červeně a označí se jako krabička vrácená na špatné místo. Opravit lze přemístěním krabičky na správné místo postupně pomocí funkce Return-box (viz níže).
- Return-box Tato funkce je vyvolána ve chvíli kdy byl načte čip na krabičce. V tu chvíli se najde v databázi kam samotná krabička patří a rozbliká se místo kam se má krabička vrátit. Po vrácení je krabička označena za vrácenou a podsvícení se změní na zelenou.
- log Tohle je zapisování jakékoliv změny do textového dokumentu například: výpůjčka, vrácení, samotné přihlášení, ukradnutý box, načtení systému po odpojení z napájení atd...

9

- box-colors Stará se o různé podsvícení jednotlivých políček podle jejich aktuálního stavu.

### 4.2 2.Thread - Flask

V tomto vlákně najdeme pouze spuštění lokálního Web-serveru a obnovování informací o aktuál-

ním stavu sestavy.

### 4.3 Web

10

## 5 Text s citacemi

Tady napíšu nějaký text a přidám k němu odkaz na zdrojovou literaturu. (Einstein 1905)

## Seznam použité literatury a zdrojů informací

Einstein, Albert (1905). „Zur Elektrodynamik bewegter Körper. (German) [On the electrodyna-
| mics of moving bodies]“. In: Annalen der Physik 322.10, s. 891–921. doi: http://dx.doi. org/10.1002/andp.19053221004. (https://doi.org/http://dx.doi.org/10.1002/andp.19053221004)

11

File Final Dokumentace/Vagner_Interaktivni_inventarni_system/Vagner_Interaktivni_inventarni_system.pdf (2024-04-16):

## Vyšší odborná škola a Střední průmyslová škola

elektrotechnická,

## Plzeň, Koterovská 85

## Ročníková práce s obhajobou

Téma: | Inteligentní inventární systém
Autor práce: | Lukáš Vágner
Třída: | 3.M
Vedoucí práce: | Ing. Pavel Jedlička
Dne: | 11. dubna 2024

## Hodnocení:

## Z A D Á N Í R O Č N Í K O V É P R Á C E

Školní rok | 2023/ 2024
Studijní obor | 78-42-M/01 Technické lyceum
Jméno a příjmení | Lukáš Vágner
Třída | 3.M
Předmět | Kybernetika
Hodnoceno v předmětu | Kybernetika
Téma | Inteligentní Inventární systémy
Obsah práce | Návrh velikosti a tvaru krabiček o Návrh designu stojanu na krabičky o Výroba samostatného stojanu o Výroba krabice na uložení mikropočítače a čtečky karet/čipu Softwarová část o Vymyslet si schéma kódu co mají dělat jed-notlivé části o Naprogramovat a zprovoznit funkčnost ce-lého systému zatím bez web-aplikaces Uživatelské rozhraní o zavedení přihlašovacího systému po-mocí kartami/čipy o Vytvoření webového rozhraní pro sledo-vání stavu inventárního systému o vizualizace inventury
Zadávající učitel Příjmení, jméno | Ing. Jedlička Pavel

## Podpis zadávajícího učitele

Termín odevzdání | 30. dubna 2024
V Plzni dne: 30. 11. 2023 | Mgr. Vlastimil Volák ředitel školy

# Vyšší odborná škola a

Střední průmyslová škola elektrotechnická Plzeň,

# Koterovská 85

## Anotace

Tato ročníková práce se zaměřuje na návrh a implementaci inteligentního inventárního systému určeného pro školní dílny. Cílem systému je efektivní evidence a správa vypůjčených položek pomocí kombinace hardwarových a softwarových technologií. Text podrobně popisuje jednotlivé části systému, včetně návrhu, hardwaru a softwaru, a také proces realizace. Hardwarová část zahrnuje použití různých komponent, jako jsou NFC/RFID čtečky, senzory a LED a jejich integraci do policového systému. Na softwarové úrovni je popsáno vytvoření systému pro správu inventáře a jeho funkce, včetně automatického sledování položek a uživatelského rozhraní pro půjčování a vrácení položek. Text dále diskutuje o možných vylepšeních a úpravách systému, které by mohly zlepšit jeho uživatelskou přívětivost a efektivitu. Celkově přináší praktický návod a náhled na implementaci inteligentního inventárního systému pro školní prostředí.

„Prohlašuji, že jsem tuto práci vypracoval samostatně a použil(a) literárních pramenů a informací, které cituji a uvádím v seznamu použité literatury a zdrojů informací.“

V Plzni dne: | Podpis:

## Obsah

1 Úvod | 5
2 Návrh | 5
3 Hardware | 7
4 Software | 9
5 Realizace | 12
6 Závěr | 14

## 1 Úvod

Tato ročníková práce se zaměřuje na návrh a implementaci inteligentního inventárního systému určeného pro školní dílny. Cílem systému je efektivní evidence a správa vypůjčovaných položek s využitím kombinace hardwarových a softwarových technologií.
| Školní dílny jsou místem, kde studenti a učitelé často vyhledávají potřebné nástroje,

součástky a další vybavení pro své projekty a experimenty. Bohužel, často dochází k nekontrolovanému vypůjčování a neúplnému navracení těchto položek, což vede k chaosu a ztrátám. Naše práce si klade za cíl tuto situaci zlepšit.
| V rámci hardwarové části projektu jsme navrhli a realizovali jednoduchý policový sys-
tém, který umožňuje systematické uskladnění a identifikaci jednotlivých položek, které jsou uskladněny ve standardních krabičkách s čipem. Tento systém využívá kombinaci NFC/RFID čtečky k rozpoznání těchto čipů ale i identifikační karty uživatelů. Díky senzorům je schopen systém rozpoznat, zda je krabička na svém místě. Dále využívá inteligentní LED pro snadnou identifikaci a signalizaci stavu jednotlivých krabiček.
| Na softwarové straně jsme vyvinuli jednoduchý systém pro správu inventáře, který
umožňuje uživatelům jednoduché a intuitivní půjčování, vrácení a sledování položek přes lokální webové rozhraní. Díky tomuto systému mohou studenti a učitelé rychle a efektivně spravovat inventář nebo hledat kdo má jednotlivé krabičky vypůjčené, popřípadě kdo jejich obsah poškodil nebo nevrátil.

## 2 Návrh

Původně jsme si představovali jednoduchý systém, který by usnadnil uskladnění krabiček a sledování jejich stavu pomocí senzorů. Vytvořili jsme několik návrhů, jak by mohla taková krabička vypadat. Celkový design poliček prošel několika změnami. Nejprve jsme uvažovali o tištěných dílech, ale nakonec jsme z těchto plánů ustoupili kvůli časovým a ekonomickým omezením. Další variantou byla klasická skříňka s celodřevěnými policemi, avšak i tento návrh jsme nakonec opustili. Po důkladné úvaze jsme se shodli na nejlepším řešení: využití dřevěných desek ze všech čtyř stran a středové desky pro rozdělení boxu na dva sloupce po pěti plastových krabičkách.
| Jako police jsme se rozhodli použít plastové úhelníky zakoupené v obchodě a pro
zadní část jsme navrhli jednoduché tištěné díly s vestavěnými senzory a LED. Elektroniku jsme také navrhli s ohledem na jednoduchou výměnu v případě potřeby s důrazem na její cenovou dostupnost a spolehlivost.
| Tento proces návrhu prošel několika iteracemi, ale nakonec jsme se dostali k řešení,
které odpovídalo našim požadavkům a omezením.

### 2.1 3D design

Návrhy všech dílů jsme dělali v Softwaru 3D CAD Inventor®, ve kterém jsme si z těchto

dílů složili celou sestavu, tak jak by celá polička měla vypadat. Jednotlivé díly jsme vyrobili a vytiskli na tiskárně nebo nařezali pilou. Zbylé díly jsme zakoupili v obchodě, a nakonec složili podle sestavy.

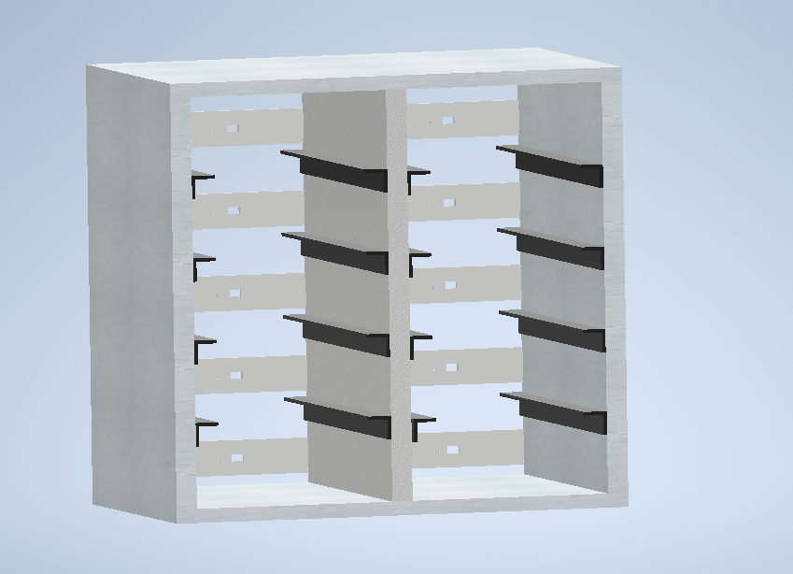
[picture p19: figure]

Obrázek 1: Vizualizace sestavy poliček

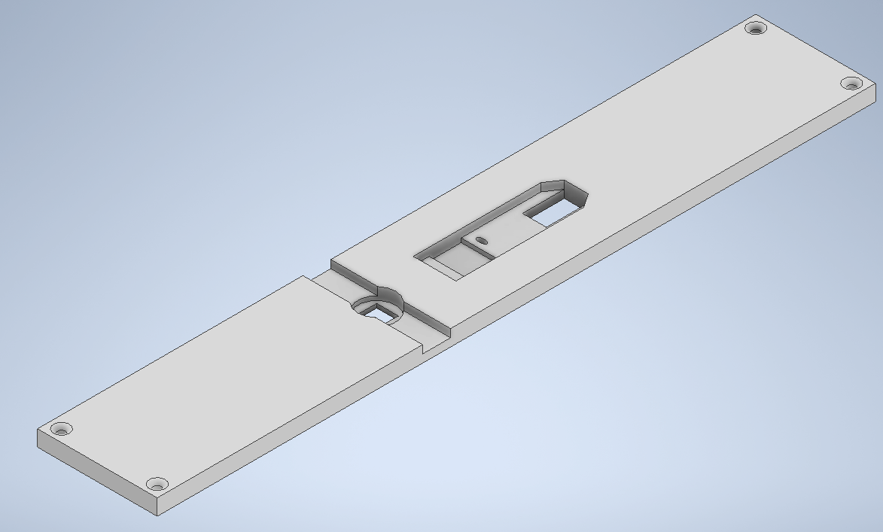
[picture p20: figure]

Obrázek 2: Vizualizace zadního bracketu

## 3 Hardware

Při výběru hardwarových komponentů jsme se zaměřili především na hotové moduly a pasivní součástky, které byly vhodné pro náš projekt.

### 3.1 Vybrané komponenty

Všechny komponenty byly pečlivě zvoleny s ohledem na jejich schopnost vzájemné komunikace a kompatibilitou s napájecími systémy. Komponenty jsou schopny pracovat s napájením buď 3.3V nebo 5V, což umožňuje jejich snadnou integraci do systému. Jako

hlavní komunikační protokol jsme se rozhodli pro I2C, což zajišťuje rychlou a spolehlivou komunikaci mezi jednotlivými komponenty.

3.1.1 Raspberry Pi Zero WH

Raspberry Pi Zero WH je kompaktní jednodeskový počítač s vestavěnou anténou pro Wifi a Bluetooth (W), což usnadňuje připojení k internetu. Jeho GPIO header umožňuje snadné připojení dalších zařízení nebo rozšíření funkcí (H). (Raspberry Pi Zero Dokumentace 2024)

Obrázek 3: Raspberry Pi Zero WH

3.1.2 Pn532 - NFC/RFID čtečka karet

Pn532 je kompatibilní s širokou škálou NFC nebo RFID karet a čipů, což z ní činí vhodnou volbu pro naší aplikaci. Připojení pomocí I2C umožňuje snadnou komunikaci s ostatními zařízeními. (Pn532 návod 2024)

Obrázek 4: NFC/RFID čtečka Pn532

3.1.3 Pcf-8575 - 16bit I/O expander pinů

Pcf-8575 rozšiřuje možnosti vstupů a výstupů Raspberry Pi, což je užitečné pro projekty s více senzory. Jeho I2C rozhraní a možnost nastavení různých adres umožňuje připojení více těchto expandérů k jednomu zařízení.

Obrázek 5: 16-bit expander Pcf-8575

3.1.4 TCRT-5000 - Infračervený optický senzor

TCRT-5000 je spolehlivý infračervený senzor vhodný pro detekci objektů nebo překážek. V našem případě jednotlivých krabiček.

Obrázek 6: Optický senzor TCRT-5000

3.1.5 WS2812B - RGB LED

WS2812B LED poskytuje jednoduchou možnost signalizace různých stavů pomocí barev. Jedná se o inteligentní LED, která umožňuje nastavení různých barevných efektů a jasů. Jejich sériové zapojení umožňuje snadné ovládání a propojení s ostatními zařízeními pouze jedním datovým vstupem.

Obrázek 7: WS2812B

### 3.2 Pasivní součástky

Kromě hotových modulů jsme také využili několik pasivních součástek pro naši aplikaci:

- LED : Použili jsme 2 LED červenou a zelenou pro vizuální signalizaci různých
| stavů.
- Buzzer: Pro zvukovou signalizaci jsme zahrnuli buzzer, který je schopen generovat
| různé zvukové signály podle aktuálního stavu systému. Buzzer přispívá k celkové interaktivitě a uživatelskému povědomí o událostech v systému.
4 | Software

Hlavní kód je psán v Pythonu. V kódu můžeme najít několik funkcí a řešení různých případů, které mohou nastat. Program běží pomocí knihovny threads ve dvou samostatných vláknech, jedno pro samotné přihlašování a vypůjčování / vracení krabiček a druhé pro lokální webový server, který běží pomocí knihovny Flask.

### 4.1 Main

V hlavním (Main) vlákně najdeme tyto funkce:

- Check-card neustálé sledování, zda byla přiložena identifikační karta nebo NFC
| čip nalepený na boxu. Když se tak stane, zavolá jiné funkce. Jestliže byl přiložen čip nějaké z krabiček zavolá funkci Return-box (viz níže). Pokud bude přiložena jakákoliv jiná karta dočasně uloží její unikátní identifikační číslo (UID).
- Check-change neustále hlídá, zda nějaký ze senzorů překážky nezaznamenal
| změnu stavu (1- krabička se zde nachází, 0 - krabička se zde nenachází). Po- kud nastane změna stavu od minulého čtení, tak funkce postupně projíždí všechny možnosti, které mohou nastat. Nejdříve jestli byla krabička vypůjčena nebo vrá- cena. Jestli že byla krabička odstraněna, ověřujeme, zda byl přihlášen uživatel. Pokud ano, zapíše se čas výpůjčky a identifikační číslo uživatele a vše je v pořádku. Pokud uživatel není přihlášen začne blikat podsvícení krabičky a přihlašovací zařízení. Na- stane 10 vteřinová prodleva, kdy má uživatel možnost se přihlásit. Za předpokladu, že se přihlásí vše se zopakuje jako kdyby již byl přihlášen. Pokud ne, je krabička označena za ukradenou a podsvícené políčko svítí červeně, dokud se nevrátí nebo tento stav není zresetován z webu. Druhá možnost: Krabička byla vrácena. V tomto případě systém ověří, zda předtím byl načten čip správné krabičky, pokud ano vše je v pořádku a zapíše se čas vrácení. Pokud předtím nebyl načten správný čip, podsvícení políčka se rozsvítí červeně a označí se jako "krabička vrácená na špatné místo".
- Return-box funkce je vyvolána ve chvíli, kdy byl načten čip krabičky. V tu chvíli se najde v databázi, kam samotná krabička patří a rozbliká se místo kam se má krabička vrátit. Po vrácení je krabička označena za vrácenou a podsvícení se změní na zelenou.
- Log je zapisování jakékoliv změny do textového dokumentu například: výpůjčka, vrácení, přihlášení, ukradnutá krabička, čas načtení systému po odpojení z napájení atd...
- Save ukládá po každé změně aktuální podobu listu DATA pro případ vypnutí systému, aby se data znovu načetla a vše se obnovilo, tak jak to bylo před vypnutím.
- Box-colors se stará o různé podsvícení jednotlivých políček podle jejich aktuálního stavu, a k tomu pouští a vypíná buzzer.

Nakonec jsou data vypsána i do konzole pythonu v podobě tabulky.

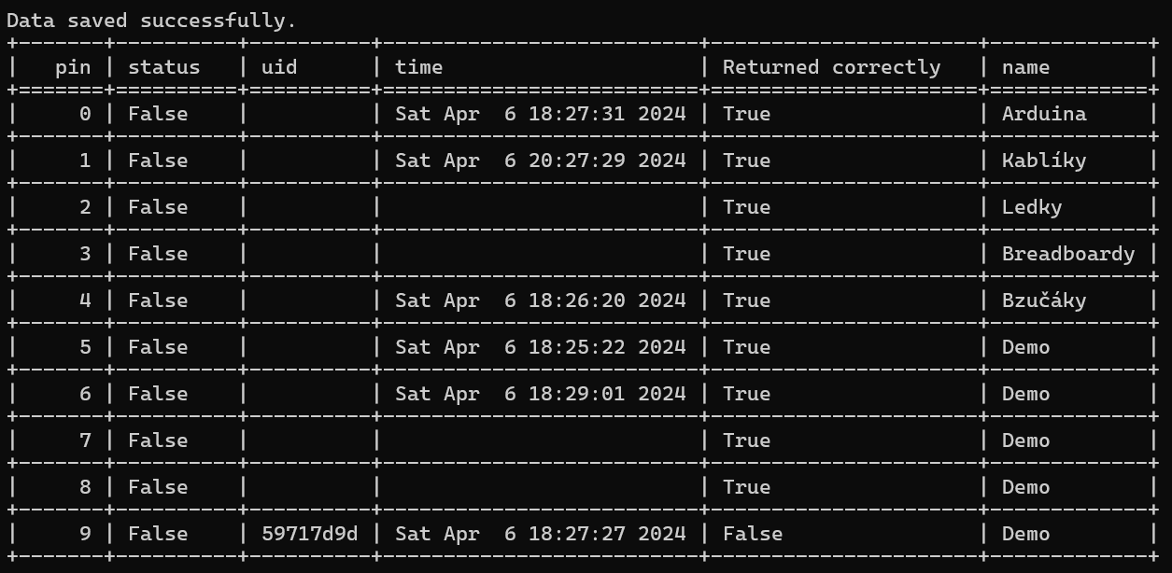
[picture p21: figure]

Obrázek 8: Tabulka aktuálních dat v terminálu

### 4.2 Flask

V tomto vlákně najdeme spuštění lokálního web-serveru a obnovování informací o aktuálním stavu sestavy. Dále funkce pro vyřizování web requestů jako třeba změna jména krabičky, vyresetování stavu a označení krabičky z webu. Ukazuje i aktuální kartu, pokud je aktivní. (Flask Dokumentace 2024)

### 4.3 Web

Web je postaven pomocí jednoduchého HTML s adaptivní tabulkou, která se nastaví podle počtu používaných senzorů automaticky. Dále jsou zde Akce: Nastavení jména krabičky, resetování stavu a probliknutí krabičky pro jednodušší nalezení. Je zde využito i CSS k samotnému designu stránky. Nakonec už je zde využitý jen templating engine JinJa, který je schopný nastavovat tabulku podle potřeb. Označit řádek s problémem pomocí červené barvy. Tento engine je používán především s Python knihovnou Flask, kterou využívám. (JinJa Dokumentace 2024)

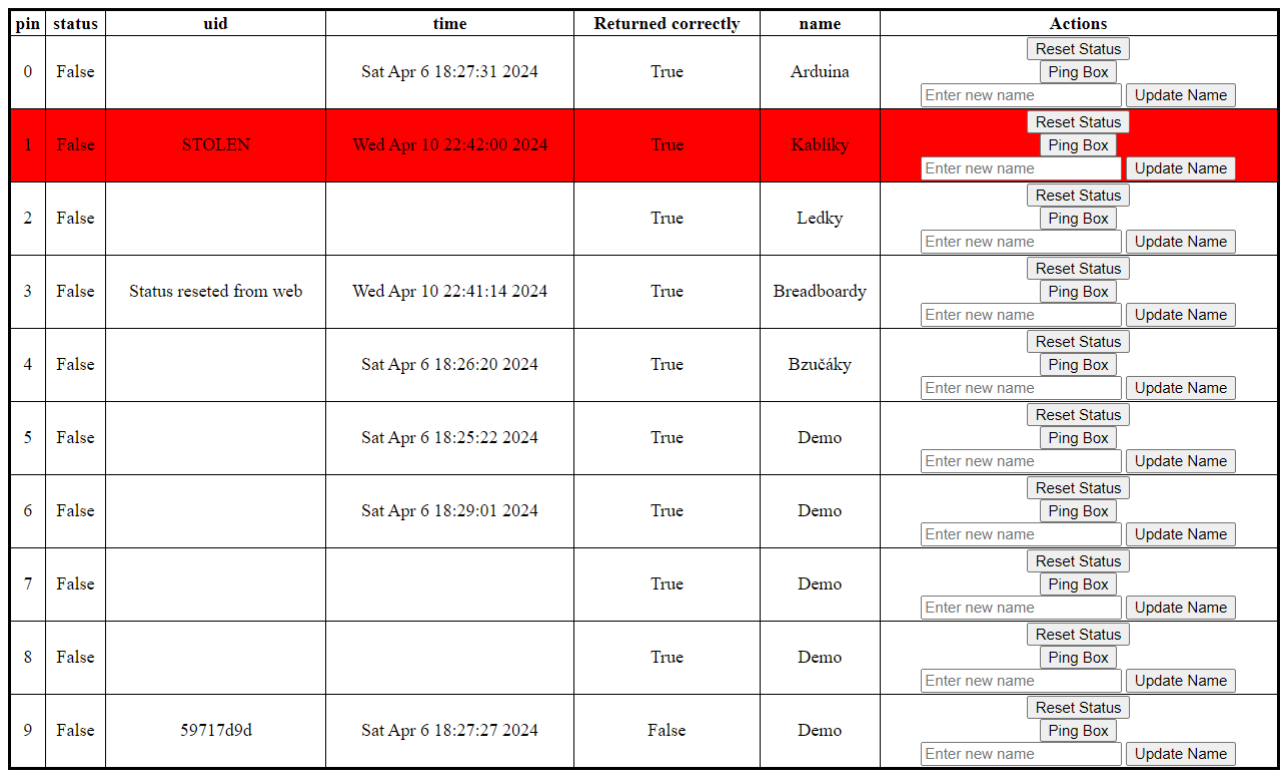
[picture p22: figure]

Obrázek 9: Web

5 | Realizace
5.1 | Zadní část poliček

V zadní části poliček najdeme 10 senzorových bracketů, které slouží i jako zarážka pro jednotlivé krabičky. Dále je zde shromažďovací bit expander ze kterého všechna data

jdou do ovládací krabičky.

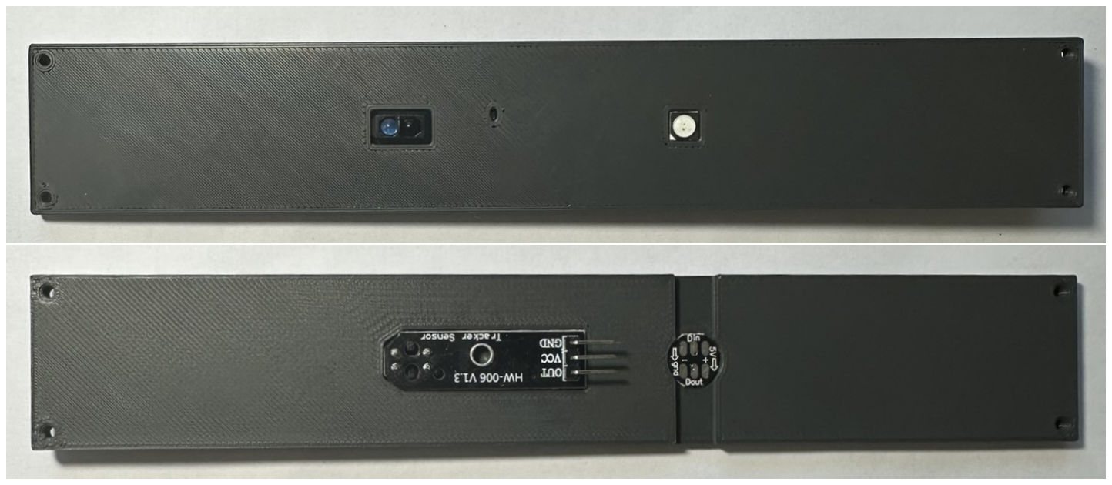
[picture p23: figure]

Obrázek 10: Senzorové brackety

### 5.2 Ovládací krabička

Samotné zařízení je uzavřeno ve speciálním 3D tištěném boxu, který zajišťuje ochranu jeho vnitřních komponentů. Na zadní straně boxu se nachází konektor sloužící k propojení se senzory zapojených do shromažďovače.

Vnitřek zařízení obsahuje NFC čtečku umístěnou v dolní části a připojenou k Raspberry Pi prostřednictvím pájivého pole. Samotné Raspberry Pi, také připojené na pájivém poli, funguje jako hlavní řídící jednotky. Ta zpracovává informace z NFC čtečky a řídí celý

systém.
Dvě LEDky, jedna červená a druhá zelená, jsou umístěny na vnější straně zařízení a slouží k vizuální signalizaci stavu. Bzučák pak poskytuje zvukový signál jako součást signalizace problému.

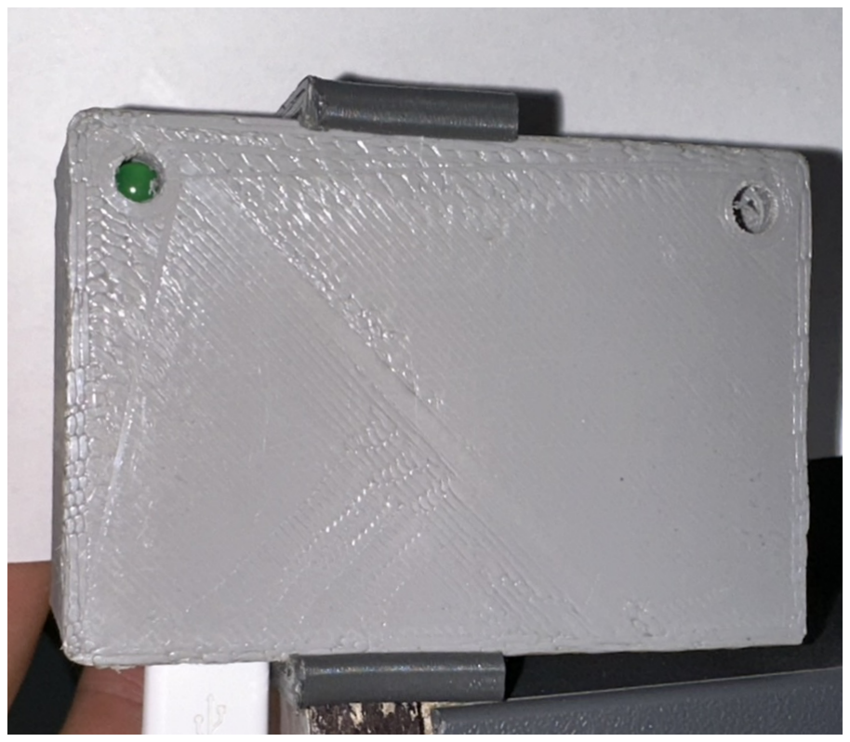
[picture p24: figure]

Obrázek 11: Ovládací krabička


Obrázek 12: Sestava v ovládací krabičce

## 6 Závěr

Naším cíle bylo vyrobit funkční inventární systém, který by řešil zapůjčování a evidenci elektronických součástek ve školních dílnách a umožňoval zobrazení aktuálního stavu na webovém rozhraní.
| Náš systém obsahuje řadu funkcí, které řeší výzvy spojené se správou krabiček ve
školních dílnách. Webový server poskytuje uživatelům přehledný pohled na aktuální obsah každého políčka, což usnadňuje lokalizaci potřebných součástek. Možnost označení hledaného políčka z webu, využitím barevného podsvícení při vizuální kontrole umožňuje rychlé a efektivní hledání. Kromě toho ukládání informací o posledních výpůjčkách poskytuje užitečné údaje pro identifikaci a správu vypůjčených položek pro případ poškození.
| Před uvedením do provozu však bude nutné provést několik úprav. Například je zapo-
třebí upravit funkce pro změnu jména krabičky a resetování statusu tak, aby byli dostupné pouze po přihlášení, aby nedocházelo ke zneužití neoprávněnými lidmi.
| Další vylepšení by mohlo spočívat v propojení systému se školní databází jmen a
identifikačních karet. Tím by se zajistilo, že každá karta je reálně přiřazena konkrétnímu žákovi či učiteli a k údajům poté přiřadit jejich jméno.
| Celkově si myslím, že náš systém je uživatelsky přívětivý a je snadný na pochopení.
To je dáno zejména signalizací, která jasně ukazuje, kam má být položka vrácena, a výstražným signálem v případě, že položka není umístěna na správném místě. Taková jednoduchá a intuitivní funkcionalita by mohla zvýšit efektivitu používání systému a minimalizovat chyby uživatelů.
| Dalším krokem bude tento systém zprovoznit ve školních dílnách a přizpůsobit jej jak
nejlépe bude možné pro všechny uživatele.


Obrázek 13: Finální podoba naší poličky

## Seznam použité literatury a zdrojů informací

Flask Dokumentace (2024). url: https://flask.palletsprojects.com/en/3.0.x/ (https://flask.palletsprojects.com/en/3.0.x/) (cit. 10. 04. 2024).

JinJa Dokumentace (2024). url: https://jinja.palletsprojects.com/en/3.1.x/ (https://jinja.palletsprojects.com/en/3.1.x/) (cit. 10. 04. 2024).

Pn532 návod (2024). url: https : / / www . elechouse . com / elechouse / images /

product/PN532_module_V3/PN532_%20Manual_V3.pdf (https://www.elechouse.com/elechouse/images/product/PN532_module_V3/PN532_%20Manual_V3.pdf) (cit. 10. 04. 2024). Raspberry Pi Zero Dokumentace (2024). url: https : / / www . raspberrypi . com /

documentation/computers/raspberry-pi.html#raspberry-pi-zero-w (https://www.raspberrypi.com/documentation/computers/raspberry-pi.html#raspberry-pi-zero-w) (cit.
10. 04. 2024).

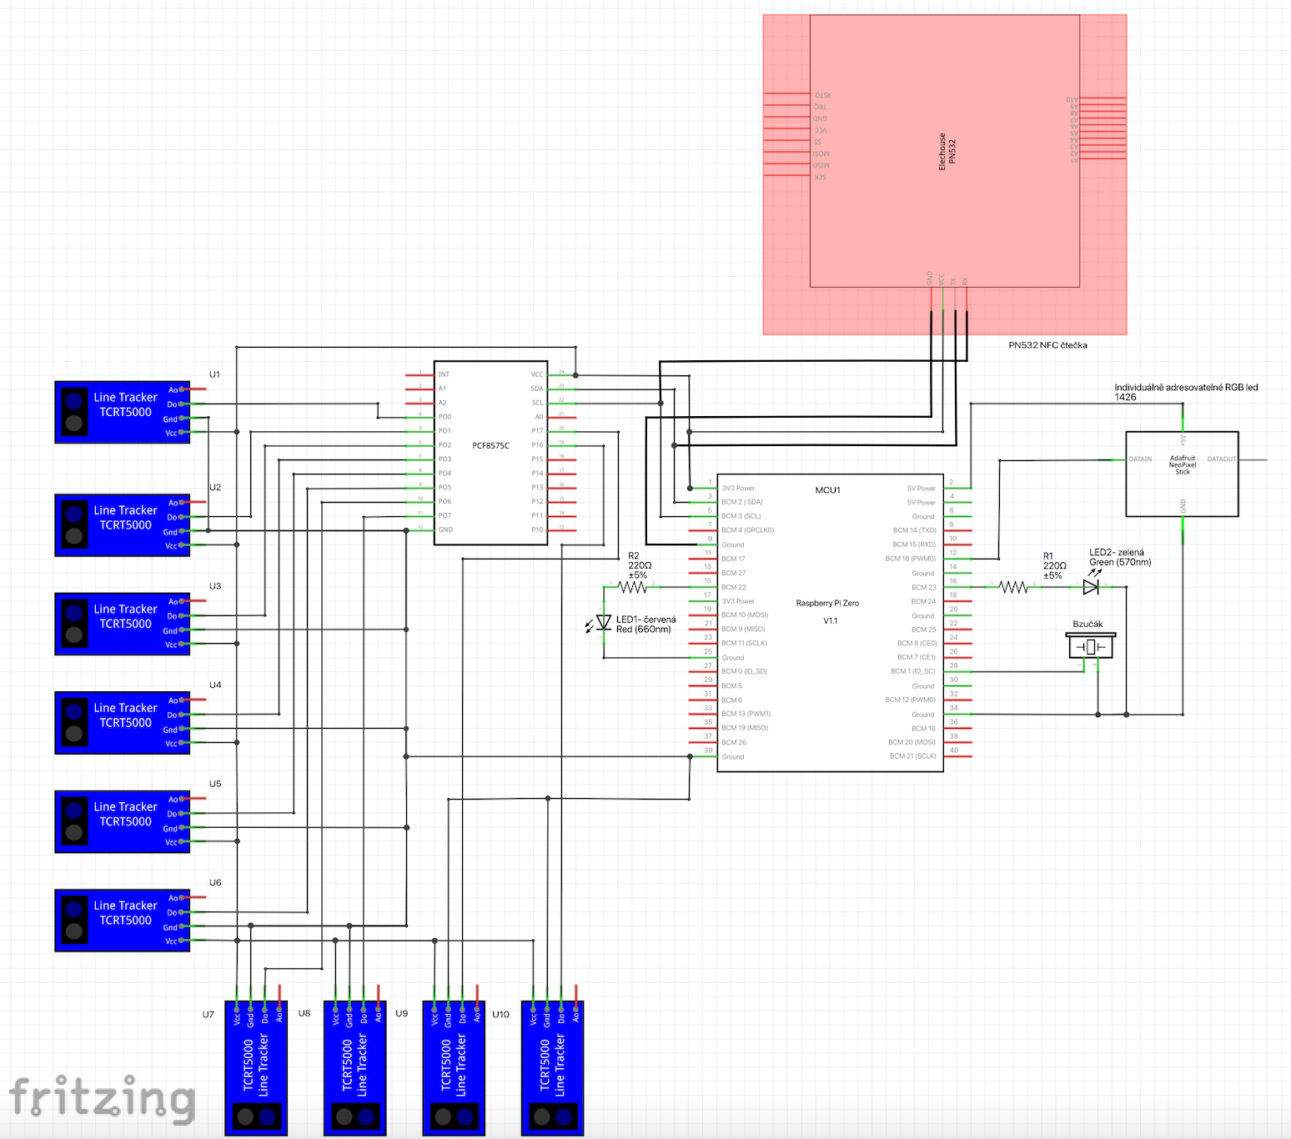
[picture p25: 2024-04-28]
Final Dokumentace/Soucek_interaktivni_inventarni_system/Prilohy/Schematic.png

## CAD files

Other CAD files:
Final Dokumentace/Soucek_interaktivni_inventarni_system/Prilohy/3D/BackboardV3.ipt
Final Dokumentace/Soucek_interaktivni_inventarni_system/Prilohy/3D/Deska_bocni.ipt
Final Dokumentace/Soucek_interaktivni_inventarni_system/Prilohy/3D/Deska_spodni.ipt
Final Dokumentace/Soucek_interaktivni_inventarni_system/Prilohy/3D/Full.iam
Final Dokumentace/Soucek_interaktivni_inventarni_system/Prilohy/3D/Úhelník.ipt
Final Dokumentace/Vagner_Interaktivni_inventarni_system/Prilohy/3D/Priloha_3_Cela_Sestava.iam
Final Dokumentace/Vagner_Interaktivni_inventarni_system/Prilohy/3D/Priloha_4_Backboard.ipt
Final Dokumentace/Vagner_Interaktivni_inventarni_system/Prilohy/3D/Priloha_5_Bocni_deska.ipt
Final Dokumentace/Vagner_Interaktivni_inventarni_system/Prilohy/3D/Priloha_7_Uhelnik.ipt
Final Dokumentace/Vagner_Interaktivni_inventarni_system/Prilohy/3D/Ptiloha_6_Deska_spodni.ipt

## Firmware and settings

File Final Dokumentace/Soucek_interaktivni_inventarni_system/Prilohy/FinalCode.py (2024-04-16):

import threading
import busio
import RPi.GPIO as GPIO
import board
from adafruit_pn532.i2c import PN532_I2C
from time import sleep, time, localtime, asctime
from tabulate import tabulate
import copy
from flask import Flask, render_template, request, redirect, url_for
from pcf8575 import PCF8575
import neopixel
import pickle
#http://192.168.0.192/

#pcf8575 setup
pcf_address = 0x20
i2c_port_num = 1
pcf = PCF8575(i2c_port_num, pcf_address)

app = Flask(__name__)

#log file setup + boot time
file = open("log.txt", "a")
file.write("Booted at: " + asctime(localtime()))
file.close()

i2c = busio.I2C(board.SCL, board.SDA)
GPIO.setmode(GPIO.BCM)

#buzzer setup
buzzer = 1
GPIO.setup(buzzer, GPIO.OUT)

#leds setup
R_led = 23
G_led = 22

GPIO.setup(R_led, GPIO.OUT)
GPIO.setup(G_led, GPIO.OUT)

uidSave = None #variable that saves the card uid
cardTime = time() 
logoutTime = 4 #time before the card is logged out in seconds
head = ["pin", "status", "uid", "time","Returned correctly","name"] #table headers
sleep(0.5)

# File paths
save_file_path = "save.pkl"
log_file_path = "log.txt"

# Save data using pickle
def save(data):
    try:
        with open(save_file_path, "wb") as save_file:
            pickle.dump(data, save_file)
        print("Data saved successfully.")
    except Exception as e:
        print(f"Error saving data: {e}")

# Load data using pickle or initialize with default values
def load():
    try:
        with open(save_file_path, "rb") as save_file:
            loaded_data = pickle.load(save_file)
        return loaded_data
    except FileNotFoundError:
        print("No save file found. Initializing with default values.")
        initial_data = [
            [0, False, "", "", True, ['0x4', '0x5b', '0xc9', '0x4b', '0x11', '0x1', '0x89'], "1"],
            [1, False, "", "", True, ['0x4', '0xa6', '0x51', '0x4b', '0x11', '0x1', '0x89'], "2"],
            [2, False, "", "", True, [], "3"],
            [3, False, "", "", True, ['0x4', '0x24', '0x4a', '0x4d', '0x11', '0x1', '0x89'], "4"],
            [4, False, "", "", True, ['0x4', '0xe5', '0x70', '0x4c', '0x11', '0x1', '0x89'], "5"],
            [5, False, "", "", True, [], "6"],
            [6, False, "", "", True, [], "7"],
            [7, False, "", "", True, [], "8"],
            [8, False, "", "", True, [], "9"],
            [9, False, "", "", True, [], "10"],
        ]
        save(initial_data)  # Save the initial data to create the file
        return initial_data
    except Exception as e:
        print(f"Error loading data: {e}")
        return None

# Load data at the beginning of the script
loaded_data = load()
if loaded_data is not None:
    DATA = loaded_data
    oldDATA = copy.deepcopy(DATA)
    print("Data loaded successfully.")
else:
    print("Initialization with default values failed. Exiting.")
    exit()

#neopixel setup
pixels = neopixel.NeoPixel(board.D18, len(DATA), brightness=255)
sleep(0.5)

#setup of the pn532 
pn532 = PN532_I2C(i2c, debug=False)
ic, ver, rev, support = pn532.firmware_version
pn532.SAM_configuration()

#setup Flask Web
def run_flask():
    app.run(debug=False, use_reloader=False, host='0.0.0.0', port=80)

#Sets colors to all boxes
def box_colors(find=False):
    if find != False:
        pixels[find] = (0, 255, 255)
        sleep(0.5)
        pixels[find] = (0, 0, 0)
        return
    buzzerOn = 0
    for i in range(len(DATA)):
        
        if DATA[i][1] == True:
            if DATA[i][4] == True:
                pixels[i] = (0, 255, 0)
                
            else:    
                pixels[i] = (255, 0, 0)
                buzzerOn = 1
        elif DATA[i][2] == "STOLEN":
            pixels[i] = (255, 0, 255)
            buzzerOn = 1
            

        else: 
            pixels[i] = (0, 0, 5)
    GPIO.output(buzzer, buzzerOn)

#Checks if the box was returned right
def return_box(i):
    return_time = time()
    
    while pcf.port[DATA[i][0]] == False:
        pixels[i] = (255, 255, 0)
        sleep(0.2)
        pixels[i] = (0, 0, 0)
        sleep(0.2)
        if time() - return_time > 4:
            break
    DATA[i][4] = True
    check_change(uidSave, i)

#checking if the boxes are still here 
def check_boxes():
    for i in range(len(DATA)):
        box_pin = DATA[i][0]
        DATA[i][1] = pcf.port[box_pin]  == True

#NFC reader always reads 
def check_card():
    global uidSave, cardTime
    pn532.SAM_configuration() #set again in case the power was out for a second
    uid = pn532.read_passive_target(timeout=0.5)

    # if new card isnt read returns old read until it isnt old than returns None
    if uid is None:
        if time() - cardTime > logoutTime:
            uidSave = None
            GPIO.output(G_led, False)
        return uidSave
    
    #dont save variable sets to True if the chip read was Box id chip 
    dontSave = False
    for i in range(len(DATA)):
        if  [hex(i) for i in uid] == DATA[i][5]:
            print("This card is a box")
            return_box(i)
            dontSave = True
            return None 
    #if its not box chip than return card uid            
    if dontSave == False:
        print("Found card with UID:", [hex(i) for i in uid])
        cardTime = time() 
        uidSave = uid
        GPIO.output(G_led, True)
        return uid

#check changes between old Data and newData than calls functions
def check_change(uid, returned_corectly):
    check_boxes()
    for i in range(len(DATA)):
        if oldDATA[i][1] != DATA[i][1]:
            if DATA[i][1] == False:
                print(f"Box {i + 1} changed")
                if uid is None:
                    print("Insert Card")
                    timeBefore = time()
                    while True:
                        print(". ")
                        GPIO.output(R_led, True)
                        uid = check_card()
                        pixels[i] = (255, 255, 0)
                        if uid is not None:
                                GPIO.output(R_led, False)
                                break
                        if time() - timeBefore > 10:
                            print("STOLEN")
                            log(f"Box {i + 1} stolen at {asctime(localtime())}")
                            DATA[i][2] = "STOLEN"
                            DATA[i][3] = asctime(localtime())
                            oldDATA[i][1] = DATA[i][1]
                            return
                DATA[i][2] = ''.join([format(byte, '02x') for byte in uid])
                DATA[i][3] = asctime(localtime())
                DATA[i][4] = False
                GPIO.output(R_led, False)
                log(f"Box {i + 1} borrowed by: {DATA[i][2]} at {DATA[i][3]}")
                oldDATA[i][1] = DATA[i][1]
            elif DATA[i][1] == True and returned_corectly == i:
                    DATA[i][2] = "RETURNED by:"+ DATA[i][2]
                    print(f"Box {i + 1} returned")
                    
                    DATA[i][3] = asctime(localtime())
                    DATA[i][4] = True
                    log(f"Box {i + 1} returned by: {DATA[i][2]} at {DATA[i][3]}")
                    oldDATA[i][1] = DATA[i][1]
            else:
                print(f"Box {i + 1} returned incorrectly")
                oldDATA[i][1] = DATA[i][1]
                DATA[i][3] = asctime(localtime())
                DATA[i][4] = False
                log(f"Box {i + 1} returned incorrectly at {DATA[i][3]}")

#writes data to log text file
def log(data):
    file = open(log_file_path, "a")
    file.write(data + "\n")
    file.close()

#main function that calls almost all functions
def main():
    while True:
        sleep(0.2)# slow down the loop
        box_colors()
        uidSave = check_card()
        check_change(uidSave, None)
        save(DATA)
        table_data = copy.deepcopy(DATA)
        table_data_trimed = [row[:-2] + [row[-1]] for row in DATA]
        print(tabulate(table_data_trimed, headers=head, tablefmt="grid"))
        print("")

# The main thread is used to check the boxes and the card
main_thread = threading.Thread(target=main)
# The flask thread is used to run the flask server
flask_thread = threading.Thread(target=run_flask)
flask_thread.start()
main_thread.start()

@app.route('/reset_stolen_status', methods=['POST'])
def reset_stolen_status():
    box_id = int(request.form['box_id'])  # Get box ID from the form data
    DATA[box_id][2] = "Status reseted from web"  # Reset the status of the box to an empty string
    DATA[box_id][4] = True  # Set the "Returned correctly" status to True
    DATA[box_id][3] = asctime(localtime())
    save(DATA)  # Save the updated data
    return redirect(url_for('index'))

@app.route('/update_box_name', methods=['POST'])
def update_box_name():
    box_id = int(request.form['box_id'])  # Get box ID from the form data
    new_name = request.form['new_name']   # Get new name from the form data
    DATA[box_id][6] = new_name            # Update the box name in the data
    save(DATA)                            # Save the updated data
    return redirect(url_for('index'))

@app.route('/find_box', methods=['POST'])
def find_box():
    box_id = int(request.form['box_id'])  # Get box ID from the form data                                     
    box_colors(box_id)                     # Set the colors of the boxes
    return redirect(url_for('index'))

@app.route('/')
def index():
    table_data_trimed = [row[:-2] + [row[-1]] for row in DATA]
    table_data = copy.deepcopy(table_data_trimed)  
    uidR = uidSave
    return render_template('index.html', table_data=table_data, headers=head, uid=uidR)

if __name__ == '__main__':
    while True:
        sleep(1)

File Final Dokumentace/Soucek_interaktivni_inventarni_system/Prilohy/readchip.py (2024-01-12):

import busio
import RPi.GPIO as GPIO
import board
from adafruit_pn532.i2c import PN532_I2C
from time import sleep, time, localtime, asctime

i2c = busio.I2C(board.SCL, board.SDA)


pn532 = PN532_I2C(i2c, debug=False) #setup pn532
ic, ver, rev, support = pn532.firmware_version #get firmware version
pn532.SAM_configuration()

uidT= ['0x4', '0x92', '0x9c', '0x4b', '0x11', '0x1', '0x89']
def check_card():
    # Check if a card is available to read if yes save it
    uid = pn532.read_passive_target(timeout=0.5)
    # Try again if no card is available.
     
    # Check if a card is available to read if yes save it
    if uid is None:
        return 
    print("Found card with UID:", [hex(i) for i in uid])
    if uidT == [hex(i) for i in uid] :
        print("This card is a box")
    print(uid)
    return uid



while True:
    print (check_card())
    sleep(1)    

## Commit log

2024-01-25 Fix bug in login functionality Add validation for user input Refactor code for better performance Update README with new instructions Fix formatting issues in CSS file
    [test2.py]
2024-04-28 3Dfiles uploaded
    [BackboardV3.ipt, Deska_bocni.ipt, Deska_spodni.ipt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]
